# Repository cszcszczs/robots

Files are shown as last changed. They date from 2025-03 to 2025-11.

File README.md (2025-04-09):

# Robots (Velocista y Sumo)

##  Esquema de montaje

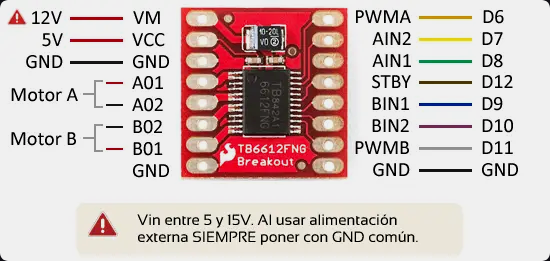
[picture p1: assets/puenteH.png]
puente h


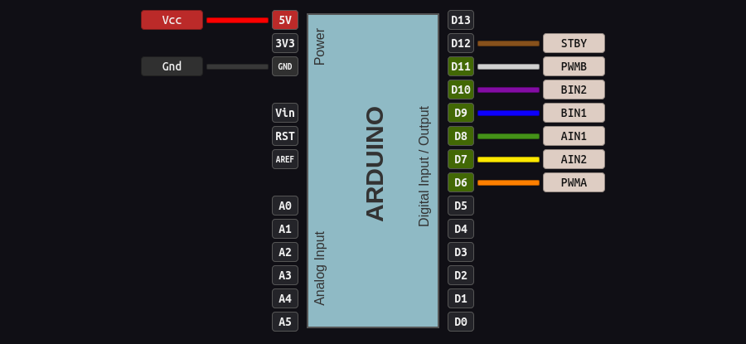
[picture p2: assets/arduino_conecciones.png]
arduino conecciones


### *fuente esquemas: https://www.luisllamas.es/arduino-motor-dc-tb6612fng/*
### *fuente codigo base sumo: https://www.youtube.com/watch?v=NjcQ3KwS5uU&t=53s*

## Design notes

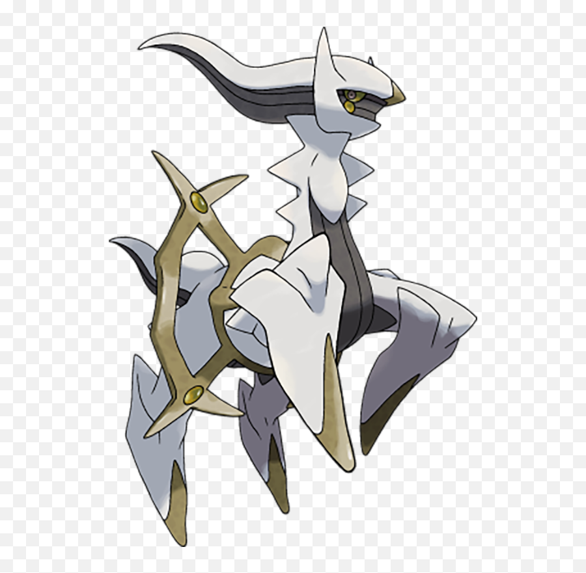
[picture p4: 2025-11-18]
sumo-architecture/image/arceus.png

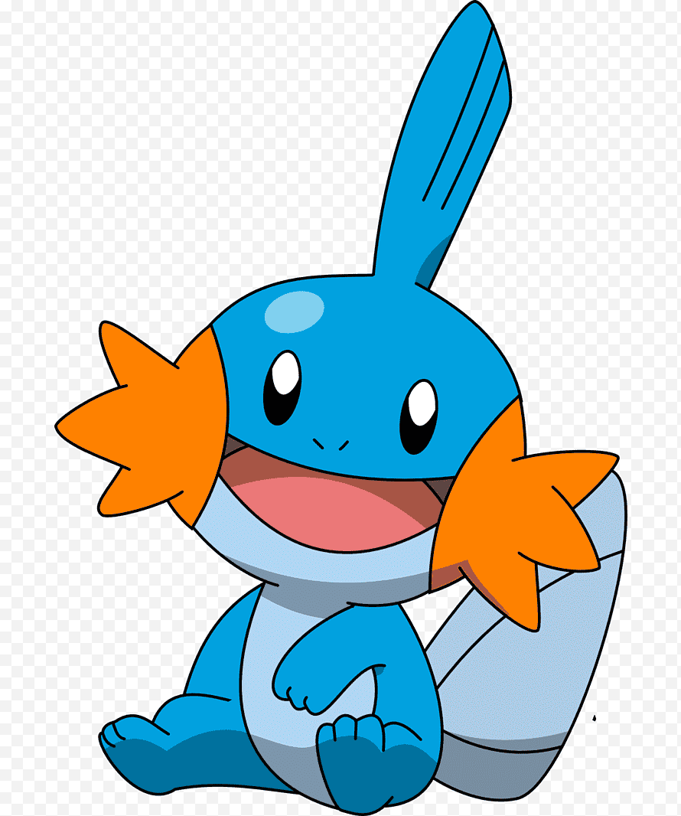
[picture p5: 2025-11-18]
sumo-architecture/image/mudkip.png

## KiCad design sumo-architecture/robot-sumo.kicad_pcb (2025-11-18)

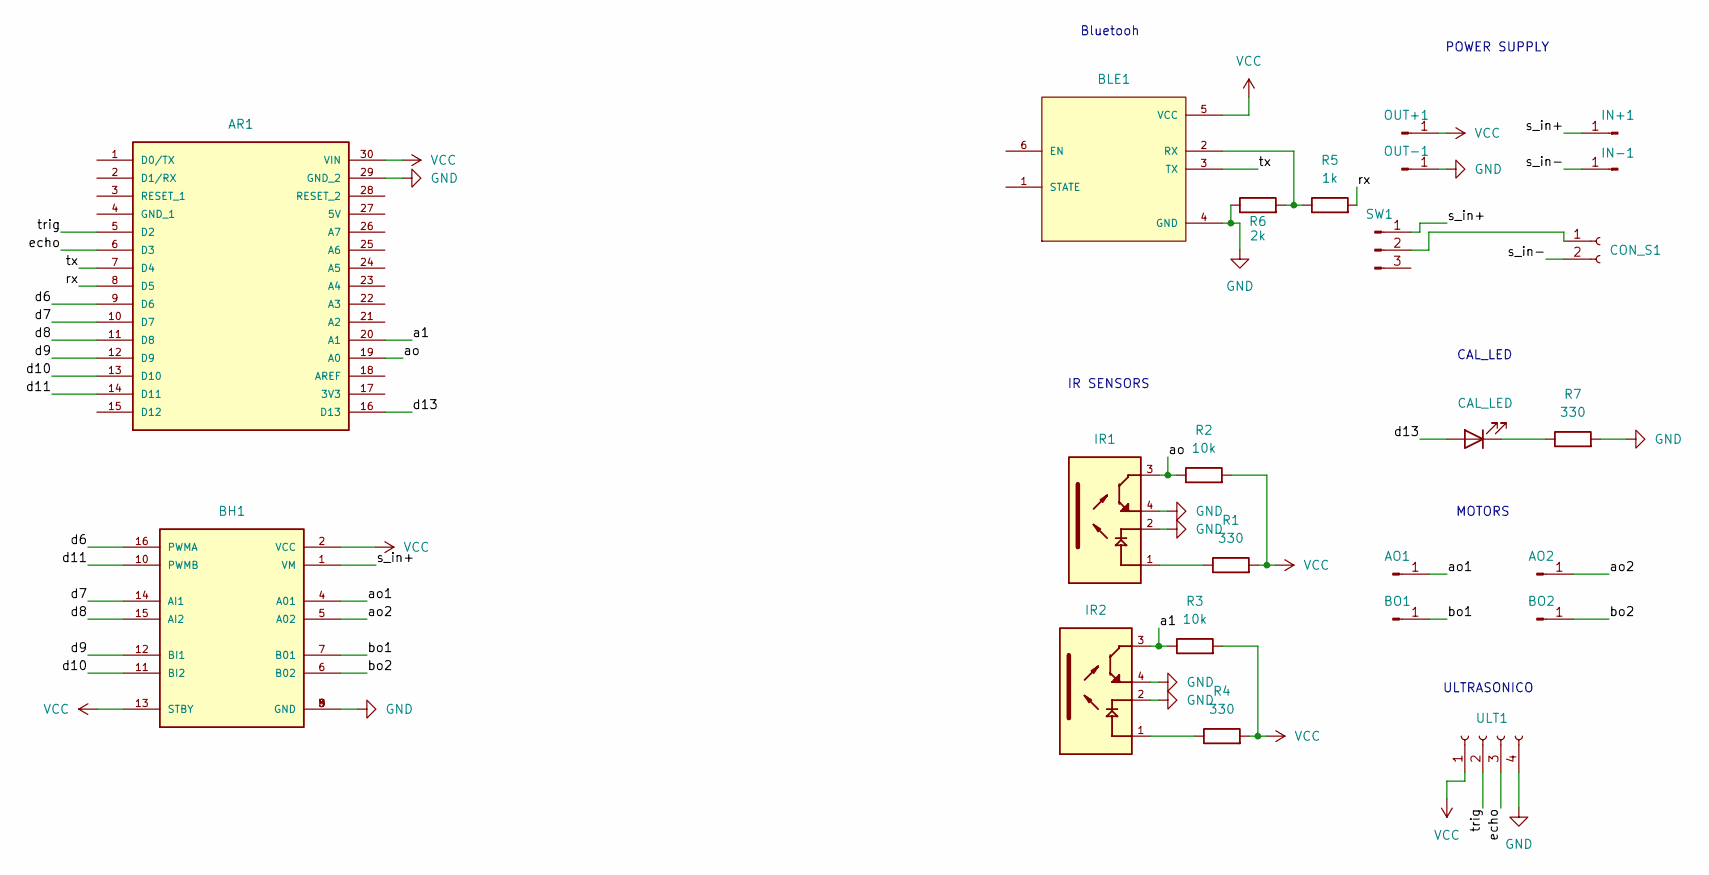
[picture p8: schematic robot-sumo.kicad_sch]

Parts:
AO1, AO2: Conn_01x01_Pin; PinHeader_1x01_P1.00mm_Vertical
AR1: A000005; MODULE_A000005; PARTREV 23/03/2020
BH1: ROB-14450; MODULE_ROB-14450; PARTREV 11-13-17
BLE1: ZC142200; MODULE_ZC142200; PARTREV N/A
BO1, BO2: Conn_01x01_Pin; PinHeader_1x01_P1.00mm_Vertical
CAL_LED1: CAL_LED; LED_D5.0mm
CON_S1: Conn_01x02_Socket; AMASS_XT60-M_1x02_P7.20mm_Vertical
IN+1: Conn_01x01_Pin; PinHeader_1x01_P1.00mm_Vertical
IN-1: Conn_01x01_Pin; PinHeader_1x01_P1.00mm_Vertical
IR1, IR2: QRE1113; DIP400W50P180L360H200Q4; PARTREV 5
OUT+1: Conn_01x01_Pin; PinHeader_1x01_P1.00mm_Vertical
OUT-1: Conn_01x01_Pin; PinHeader_1x01_P1.00mm_Vertical
R1, R4, R7: 330; R_Axial_DIN0204_L3.6mm_D1.6mm_P7.62mm_Horizontal
R2, R3: 10k; R_Axial_DIN0204_L3.6mm_D1.6mm_P7.62mm_Horizontal
R5: 1k; R_Axial_DIN0204_L3.6mm_D1.6mm_P7.62mm_Horizontal
R6: 2k; R_Axial_DIN0204_L3.6mm_D1.6mm_P7.62mm_Horizontal
SW1: Conn_01x03_Pin; PinHeader_1x03_P1.00mm_Vertical
ULT1: Conn_01x04_Socket; PinHeader_1x04_P2.00mm_Vertical

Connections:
/a1: AR1.20 (A1), IR2.3, R3.1
/ao: AR1.19 (A0), IR1.3, R2.1
/ao1: AO1.1, BH1.4 (A01)
/ao2: AO2.1, BH1.5 (A02)
/bo1: BH1.7 (B01), BO1.1
/bo2: BH1.6 (B02), BO2.1
/d6: AR1.9 (D6), BH1.16 (PWMA)
/d7: AR1.10 (D7), BH1.14 (AI1)
/d8: AR1.11 (D8), BH1.15 (AI2)
/d9: AR1.12 (D9), BH1.12 (BI1)
/d10: AR1.13 (D10), BH1.11 (BI2)
/d11: AR1.14 (D11), BH1.10 (PWMB)
/d13: AR1.16 (D13), CAL_LED1.2 (A)
/echo: AR1.6 (D3), ULT1.3
/rx: AR1.8 (D5), R5.2
/s_in+: BH1.1 (VM), IN+1.1, SW1.1
/s_in-: CON_S1.2, IN-1.1
/trig: AR1.5 (D2), ULT1.2
/tx: AR1.7 (D4), BLE1.3 (TX)
GND: AR1.29 (GND_2), BH1.3 (GND), BH1.8 (GND), BH1.9 (GND), BLE1.4 (GND), IR1.2, IR1.4, IR2.2, IR2.4, OUT-1.1, R6.1, R7.2, ULT1.4
unnamed: BLE1.2 (RX), R5.1, R6.2
unnamed: CAL_LED1.1 (K), R7.1
unnamed: CON_S1.1, SW1.2
unnamed: IR1.1, R1.1
unnamed: IR2.1, R4.1
VCC: AR1.30 (VIN), BH1.2 (VCC), BH1.13 (STBY), BLE1.5 (VCC), OUT+1.1, R1.2, R2.2, R3.2, R4.2, ULT1.1

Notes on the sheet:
POWER SUPPLY
ULTRASONICO
IR SENSORS
Bluetooh
CAL_LED
MOTORS

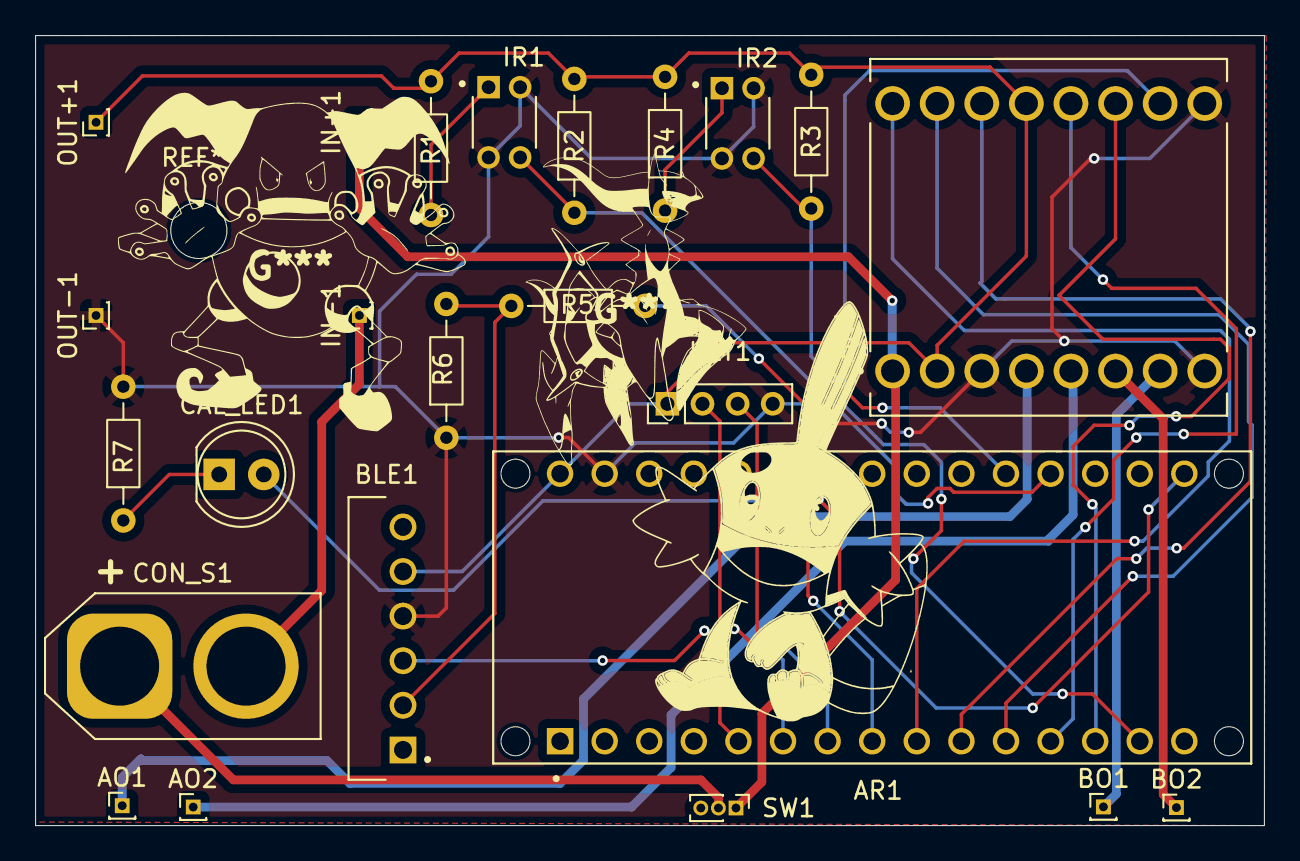
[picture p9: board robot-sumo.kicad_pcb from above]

Board: 2 copper layers, 70.0 x 45.0 mm, 24 parts (0 on the bottom side), 26 nets.

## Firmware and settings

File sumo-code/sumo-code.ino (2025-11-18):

/*
  SENSOR IR
  negro - HIGH
  blanco - LOW
*/
#include "motors.h"
#include "Ir.h"

#define IR_A 11
#define IR_B 4
#define TRIG_PIN 2
#define ECHO_PIN 3

Motors motors = Motors(11, 6, 9, 10, 7, 8);
//Motors motors = Motors(11, 6, 9, 10, 7, 8);
IR sensores[8] = { IR(A0), IR(A1), IR(A2), IR(A3), IR(A4), IR(A5), IR(A6), IR(A7) };
unsigned int distance;

bool back = false;
bool search = false;
bool attack = false;
bool last_turn = false;
bool sum = false;
short count_turn = 0;

bool state = false;
bool pressed = false;

const int BTN_PIN = 4;

void calibrar_sensores(IR (&sensores)[8], uint16_t pin, uint8_t n) {
  for (size_t i = 0; i < n; i++) {
    int blanco = sensores[i].calibrar_color(pin);
    delay(1500);
    int negro = sensores[i].calibrar_color(pin);

    if (blanco < negro) {
      sensores[i].set_white(blanco);
      Serial.println(blanco);
    } else {
      sensores[i].set_white(negro);
      Serial.println(negro);
    }
  }
}


void setup() {
  Serial.begin(9600);

  pinMode(BTN_PIN, INPUT);

  pinMode(TRIG_PIN, OUTPUT);
  pinMode(ECHO_PIN, INPUT);
  pinMode(12, HIGH);

  motors.init();
  motors.config_direction(1, 0);
  digitalWrite(12, HIGH);
  
  motors.set_pwa(130);
  motors.set_pwb(90);

  calibrar_sensores(sensores, 13, 2);
  for (int i = 0; i < 2; i++)
  {
    Serial.print("Sensor ");
    Serial.print(i);
    Serial.print(": ");
    Serial.println(sensores[i].get_white());
  }

    // SON 5
  delay(1000);
}

void loop() {
  // go to backward
  if (!sensores[0].value() && !sensores[1].value()) {
    backward();
    attack = false;
    sum = 0;
  }
  // turn right
  else if (!sensores[0].value() && sensores[1].value()) {
    turn_right();
    attack = false;
    last_turn = true;
    sum++;
  }
  // turn left
  else if (sensores[0].value() && !sensores[1].value()) {
    turn_left();
    attack = false;
    last_turn = false;
    sum++;
  }
  // go to forward  
  else {
    ult_sensor();

    if (attack) {
      motors.set_pwa(255);
      motors.set_pwb(235);
      motors.forward();
      count_turn = 0;

      if (distance > 30) {
        attack = false;
      }
    }
    else if (enemy_in_distance()) {
      before_attack();
    }
    else {
      if (count_turn >= 3) {
        bool next = false;
        count_turn = 0;
        motors.set_pwa(150);
        motors.set_pwb(150);
        
        if (last_turn) {
          motors.A_forward();
          motors.B_backward();
          delay(100);
        }
        else {
          motors.B_forward();
          motors.A_backward();
          delay(100);
        }
      }
      else {
        motors.set_pwa(50); //100
        motors.set_pwb(60); // 90
        motors.forward();
      }
    }
  }
}

void backward() {
  back = true;
  motors.set_pwa(140);
  motors.set_pwb(140);
  motors.backward();

  if (sensores[0].value() || sensores[1].value()) {
    motors.set_pwa(100);
    motors.set_pwb(100);
    if (sensores[0].value() && sensores[1].value()) {
      back = false;
    }
    else if (sensores[0].value()) {
      motors.A_backward();
      motors.B_forward();
      delay(100);
    }
    else {
      motors.A_forward();
      motors.B_backward();
      delay(100);
    }
  }
}

void turn_right() {
  motors.set_pwa(200);
  motors.set_pwb(200);
  motors.A_backward();
  motors.B_forward();
  delay(100);
}

void turn_left() {
  motors.set_pwa(200);
  motors.set_pwb(200);
  motors.B_backward();
  motors.A_forward();
  delay(100);
}

void ult_sensor() {
  delay(10);
  digitalWrite(TRIG_PIN, LOW);
  delayMicroseconds(2);

  digitalWrite(TRIG_PIN, HIGH);
  delayMicroseconds(10);
  digitalWrite(TRIG_PIN, LOW);

  distance = pulseIn(ECHO_PIN, HIGH) * 0.034/2;
}

bool enemy_in_distance() {
  ult_sensor();
  return distance <= 20;
}

void before_attack() {
  motors.stop();
  uint16_t p = distance;
  delay(20);
  ult_sensor();

  if (p <= distance) attack = true;
  else search = true;
}

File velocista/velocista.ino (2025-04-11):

const int velA = 6;
const int velB = 11;
const int Ain2 = 7;
const int Ain1 = 8;
const int stby = 12;
const int Bin1 = 9;
const int Bin2 = 10;

// sensores
const int sensorA0 = A0;

// valores sensores
int valorSensorA0;

// Definir variables para encontrar el promedio linea negra
const int numLecturas = 10; // Número de lecturas para calcular el promedio
float lineaNegra;

void setup() {
  // motores
  pinMode(velA, OUTPUT);
  pinMode(velB, OUTPUT);
  pinMode(Ain2, OUTPUT);
  pinMode(Ain1, OUTPUT);
  pinMode(stby, OUTPUT);
  pinMode(Bin1, OUTPUT);
  pinMode(Bin2, OUTPUT);

  // sensores
  pinMode(sensorA0, INPUT);

  analogWrite(velA, 255);
  analogWrite(velB, 255);
  digitalWrite(stby, HIGH);

  // encontrar el promedio de la linea negra
  lineaNegra = promedioLinea();
}

void loop() {
  // leer los valores de los sensores
  valorSensorA0 = analogRead(sensorA0);
  // Adelante
  digitalWrite(Ain1, LOW);
  digitalWrite(Ain2, HIGH);

  digitalWrite(Bin1, LOW);
  digitalWrite(Bin2, HIGH);

  delay(2000);

  //Atras
  digitalWrite(Ain1, HIGH);
  digitalWrite(Ain2, LOW);

  digitalWrite(Bin1, HIGH);
  digitalWrite(Bin2, LOW);
  
  delay(2000);
  
}

// Funcion para encontrar la media de la linea negra
float promedioLinea() {
  int suma = 0;
  for(int i = 0; i < numLecturas; i++) {
    int lectura = analogRead(sensorA0);
    suma += lectura;
    delay(100);
  }

  return suma / numLecturas;
}

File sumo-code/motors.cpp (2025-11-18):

#include "HardwareSerial.h"
#include <Arduino.h>
#include "motors.h"

Motors::Motors(uint8_t PWA, uint8_t PWB, uint8_t AIN1, uint8_t AIN2, uint8_t BIN1, uint8_t BIN2) {
  pwa = PWA;
  pwb = PWB;
  ain1 = AIN1;
  ain2 = AIN2;
  bin1 = BIN1;
  bin2 = BIN2;
}

void Motors::init() {
  pinMode(pwa, OUTPUT);
  pinMode(pwb, OUTPUT);

  pinMode(ain1, OUTPUT);
  pinMode(ain2, OUTPUT);
  pinMode(bin1, OUTPUT);
  pinMode(bin2, OUTPUT);

  Serial.println("[M] Configured motor pins.");
}

void Motors::config_direction(uint8_t A, uint8_t B) {
  if (A) {
    A_direction[0] = ain2;
    A_direction[1] = ain1;
  }
  else {
    A_direction[0] = ain1;
    A_direction[1] = ain2;
  }

  if (B) {
    B_direction[0] = bin2;
    B_direction[1] = bin1;
  }
  else {
    B_direction[0] = bin1;
    B_direction[1] = bin2;
  }
}

void Motors::set_pwa(uint16_t vel) {
  analogWrite(pwa, vel);
}

void Motors::set_pwb(uint16_t vel) {
  analogWrite(pwb, vel);
}

void Motors::forward() {
  A_forward();
  B_forward();
}

void Motors::backward() {
  A_backward();
  B_backward();
}

void Motors::A_forward() {
  digitalWrite(A_direction[0], HIGH);
  digitalWrite(A_direction[1], LOW);
}

void Motors::B_forward() {
  digitalWrite(B_direction[0], HIGH);
  digitalWrite(B_direction[1], LOW);
}

void Motors::A_backward() {
  digitalWrite(A_direction[0], LOW);
  digitalWrite(A_direction[1], HIGH);
}

void Motors::B_backward() {
  digitalWrite(B_direction[0], LOW);
  digitalWrite(B_direction[1], HIGH);
}

void Motors::A_stop() {
  digitalWrite(A_direction[0], LOW);
  digitalWrite(A_direction[1], LOW);
}

void Motors::B_stop() {
  digitalWrite(B_direction[0], LOW);
  digitalWrite(B_direction[1], LOW);
}

void Motors::stop() {
  A_stop();
  B_stop();
}

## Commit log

2025-03-26 agregando el readme
2025-03-26 agregando carpeta assets y modificando el readme
2025-03-26 renombrando carpeta seguidor_linea a velocista
2025-04-11 cambiando puertos del sumo y agregando el codigo de sensores para calibrar y verifivar informacion
2025-04-29 Reorganize arduino and h bridge
2025-05-06 Create sumo PCB
2025-05-09 Add leds on the PCB
2025-05-13 Add button on PCB and modify calibrate button circuit
2025-11-10 update sumo pcb and its code
2025-11-10 Add sumo PCB folder
    [robot-sumo.kicad_pcb, robot-sumo.kicad_sch]
2025-11-10 Add sumo PCB backups
2025-11-10 🚀 Sumo code refactor #1
